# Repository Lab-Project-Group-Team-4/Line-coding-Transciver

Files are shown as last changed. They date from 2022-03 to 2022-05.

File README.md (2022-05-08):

# Line-coding-Transciver
Line coding is a technique which is used to transmit a bit stream using a channel. There are several 
globally recognized standard line-coding schemes available in the world. This paper focuses on the 
development and implementation of a simplex line coding transceiver based on analog components 
and IC’s such as OpAmps, transistors and signal generating ICs. This project aims to accomplish 
data between two microcontrollers via a pair of twisted wires transmission with a data length of 1000 
bits at a minimum data rate of 10 kb/s

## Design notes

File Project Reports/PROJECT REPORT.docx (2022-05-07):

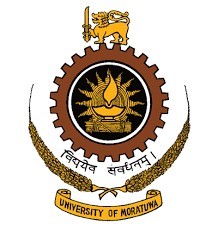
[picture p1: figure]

Department of Electronic & Telecommunication Engineering

University of Moratuwa

Simplex Line Coding Transceiver

Group 04

Ayodya W.K.H | 190065K
Bandara D.P.S.D | 190070V
Bandara D.R.K.W.M.S.D | 190071B
Bandara E.M.D.A | 190072E

Supervisor: Mr. Mevan Wijewardena

This report is submitted as partial fulfilment of module EN2090 - Laboratory Practice - II

Date of Submission: 07th May 2022

Table of Content

| Page
Abstract | i
1. Introduction | 3
2. Methodology 2.1. Block Diagrams 2.2. Encoder Circuit 2.2.1. Specifications 2.2.2. Circuit 2.2.3. Calculations 2.2.4. Simulation 2.2.5. PCB 2.2.6. Enclosure Design 2.3. Decoder Design 2.3.1. Specifications 2.3.2. Circuit 2.3.3. Simulation 2.3.4. PCB 2.3.5. Enclosure Design | 3 - 4 4 - 7 4 5 5 6 6 - 7 7 7 - 9 7 8 8 9 9
3. Results | 10
4. Discussion | 10
5. Acknowledgements | 11
6. References /Bibliography | 11
7. Contribution | 11
8. Appendices | 11 - 18

Project Report – Semester 3 May 2022

Simplex Line Coding Transceiver

Group 4

Dept. of Electronic and Telecommunication Engineering, University of Moratuwa

ABSTRACT

Line coding is a technique which is used to transmit a bit stream using a channel. There are several globally recognized standard line-coding schemes available in the world. This paper focuses on the development and implementation of a simplex line coding transceiver based on analog components and IC’s such as OpAmps, transistors and signal generating ICs. This project aims to accomplish data between two microcontrollers via a pair of twisted wires transmission with a data length of 1000 bits at a minimum data rate of 10 kb/s.

1. INTRODUCTION

The simplex line coding transceiver transmits specific length bits via a pair of twisted wires in one direction from one location to another. The transmitter and the receiver operate on the same frequency. This project aims to transmit a large bit length at a high bit rate with a low error rate. We have designed and built an encoding circuit and a decoding circuit that includes all analog devices. We chose the Manchester encoding system as our encoding technology.

2. METHODOLOGY

Manchester Encoding scheme has been implemented in our design using separate encoder and decoder circuits connected by a 50cm long twisted pair cable.

  2.1. Block Diagrams

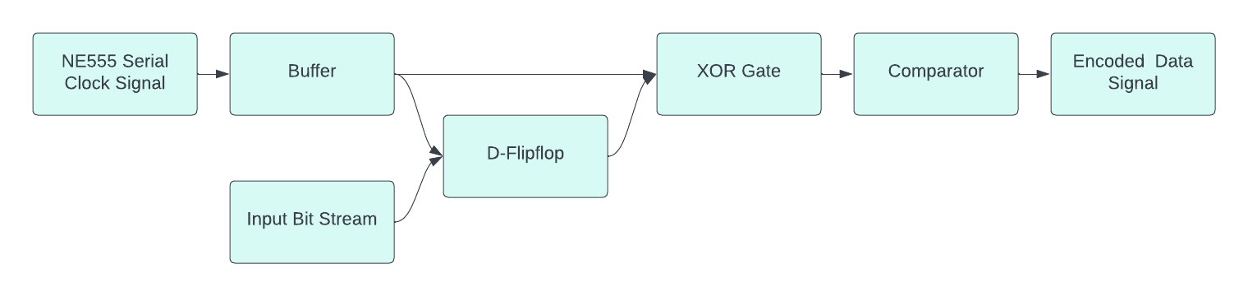
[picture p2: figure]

Figure 2.1.1: Encoder Block Diagram

- D flip flop: Syncing Data signal with the clock input
- Clock Buffer Circuit: To introduce a delay to clock pulse.
- XOR Gate: Apply XOR operation on clock and data signals to produce the output as 0V - 5V signal
- Comparator: Convert signal in to -5V to +5V signal to produce Manchester Signal

Figure 2.1.1: Decoder Block Diagram

- Transistor switches: Used to remove the rapid pulses in the Manchester signal
- Comparator: Used to remove the distortions which is added by transistor switches and make a clean signal
- Holding and thresholding part: Use to hold the levels for a fixed period.
  2.2. Encoder Design

Encoder encodes digital data into a digital signal using Manchester encoding scheme. In Manchester encoding, ‘0’s are encoded as falling edges and ‘1’s are encoded as rising edges. The main advantage of using Manchester encoding is its self-clocking and synchronization on mid-bit transition. Manchester encoded data is achieved by sending digital data and clock through an XOR gate.

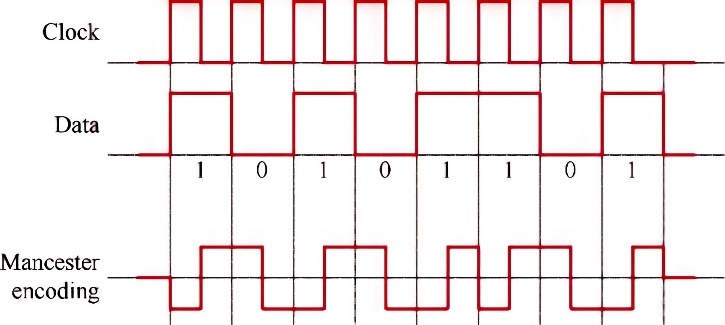
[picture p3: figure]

Figure 2.2: Manchester Encoding Scheme

    2.2.1. Specifications

Baud Rate : 10 kb/s

Current Drawn : 46 mA

Operating Voltages : 8 – 24 V

Impedance : 92 kΩ

    2.2.2. Circuit

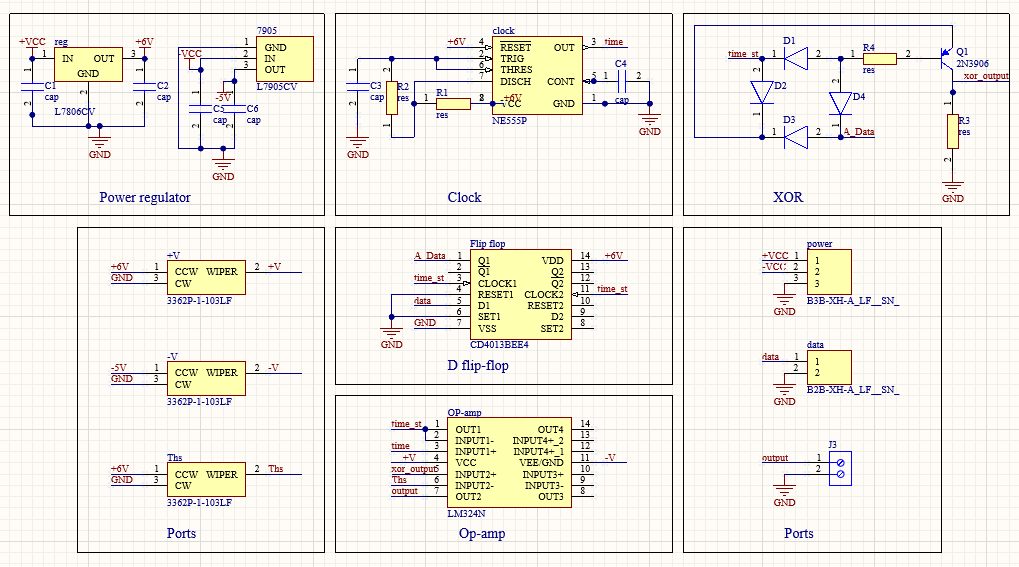
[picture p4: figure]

Figure 2.2.2: Encoder Schematic Design

    2.2.3. Calculations

The following calculations are used to derive the clock frequency and the duty cycle of the NE555 timer.

Frequency of Oscillation,

R1 = 220 Ω

R2 = 5600 Ω

C1 = 10 nF

f=1/T=(1⋅44)/((R_1 +2R_2 )C_1) = (1⋅44)/((220+2×5600)×10×10 ^(-9)) = 12 kHz

Duty Cycle,

(t_1)/(t_1 +t_2)=(R_1 +R_2)/(R_1 +2R_2)=1-(R_2)/(R_1 +2R_2) = 1-5600/(220+2×5600) = 50%

    2.2.4. Simulation

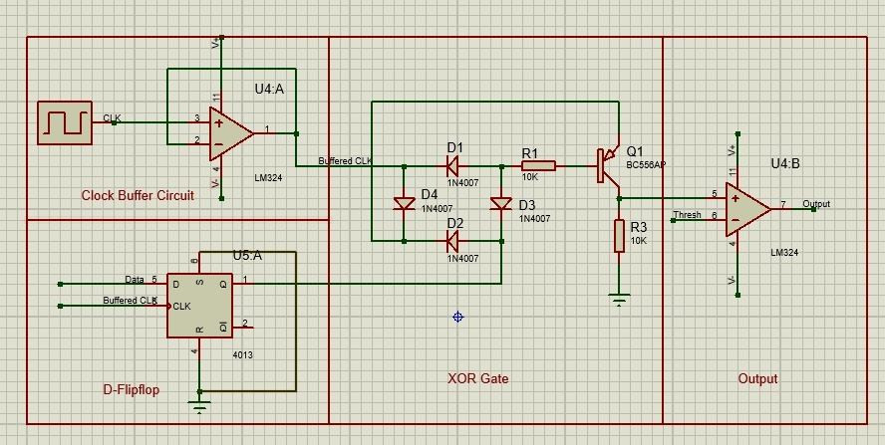
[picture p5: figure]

Figure 2.3.3: Encoder Simulation

    2.2.5. PCB Design

Size of the PCB : 9cm x 5cm

Components mounted on Encoder PCB

- LM7905 Voltage Regulator - 1
- LM7806 Voltage Regulator - 1
- CD4013B D-Flipflop IC - 1
- NE555 Timer - 1
- LM324N OpAmp - 1
- BC556 PNP Transistor - 1
- Capacitors
  - 100 nF Polarized Cap - 2
  - 10 nF Ceramic Cap - 1
  - 100 nF Ceramic Cap - 1
  - 330 nF Polarized Cap - 2
- Resistors
  - 10 kΩ - 2
  - 5.6 kΩ - 1
  - 220 Ω - 1
- 1k Potentiometer - 3
- 1N4007 Diodes - 4
- 3 pin JST Connector - 1
- Screw Terminal - 1

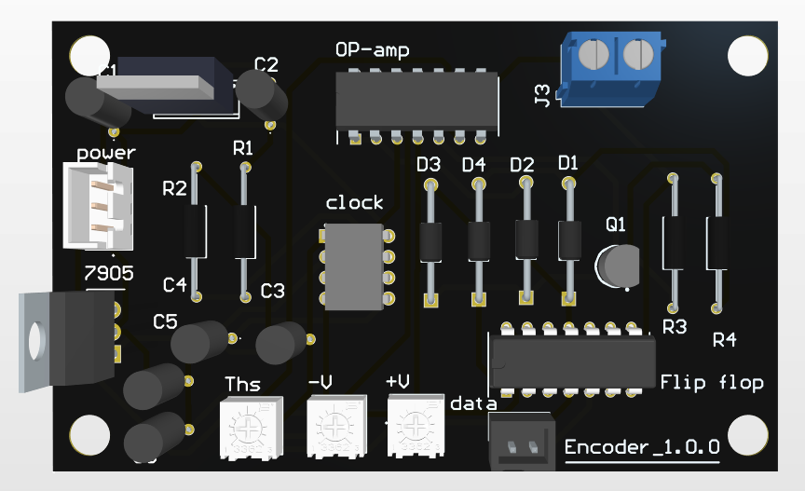
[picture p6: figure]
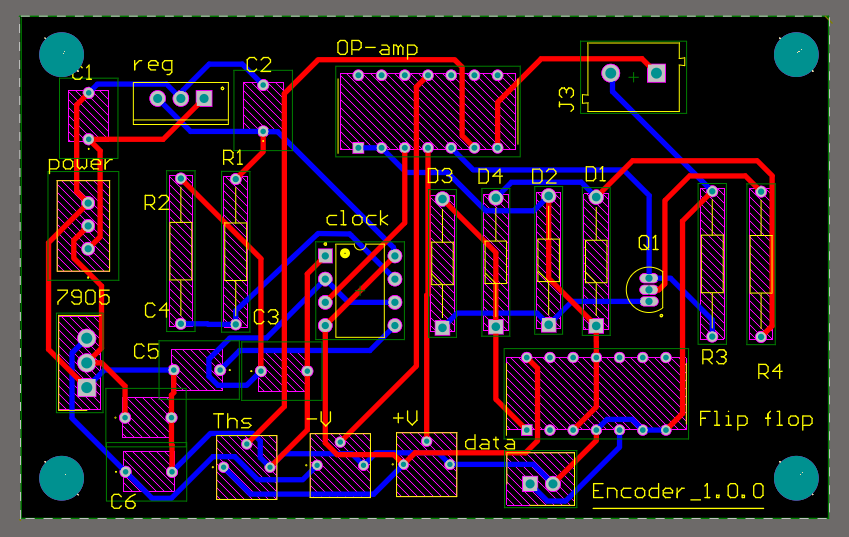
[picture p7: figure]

Figure 2.2.5.1: Encoder PCB 3D Model Figure 2.2.5.2: Encoder PCB Design

    2.2.6. Enclosure Design

The enclosure is design with a glossy finish to get a futuristic appearance.

Material : PLA+ Plastics

Size of the Enclosure : 9cm x 5.6cm x 5.6cm

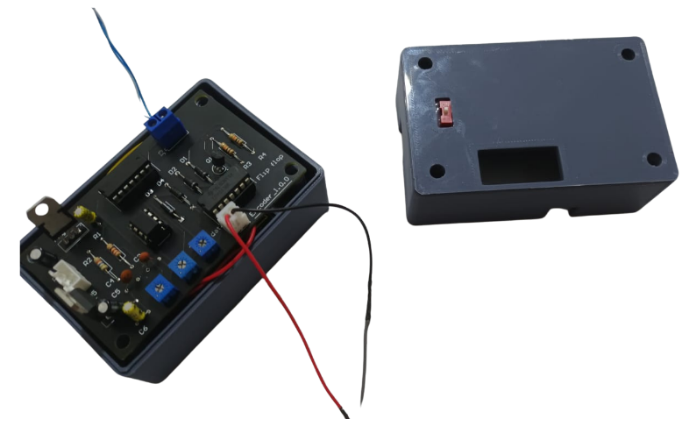
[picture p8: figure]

Figure 2.2.6: Encoder Enclosure Design

  2.3. Decoder Design

The decoding circuit consist only analog components. When the encoded Manchester signal is received, the encoded data is decoded by the decoder. The decoder circuit operates at a frequency very similar to the encoder circuit.

    2.3.1. Specifications

Baud Rate : 10 kb/s

Current Drawn : 17 mA

Operating Voltages : 8 – 24 V

Impedance : 92 kΩ

    2.3.2. Circuit

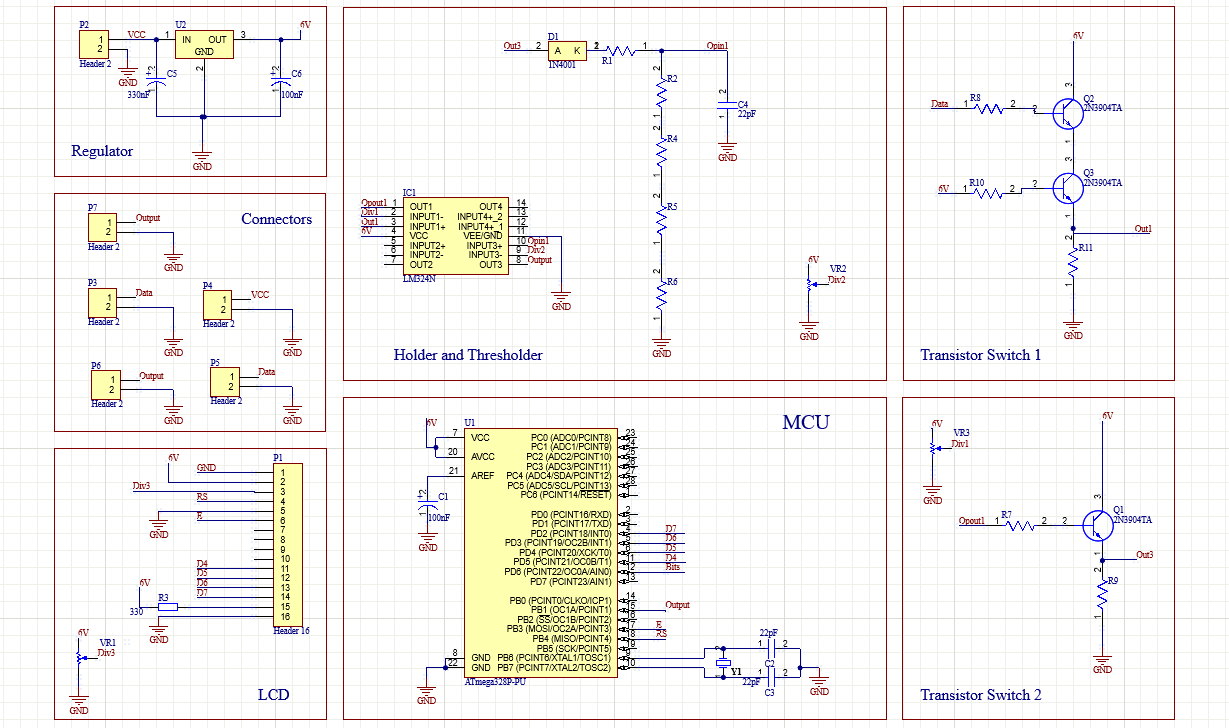
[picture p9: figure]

Figure 2.3.2: Decoder Schematic Design

    2.3.3. Simulation

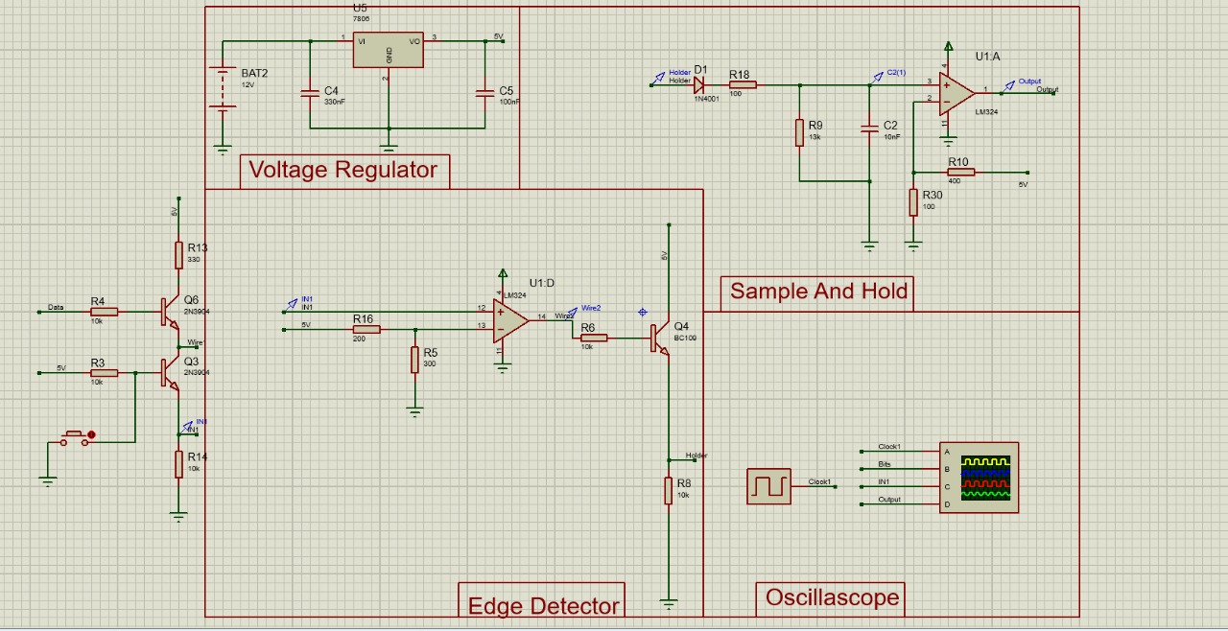
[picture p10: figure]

Figure 2.3.3: Decoder Simulation

    2.3.4. PCB Design

Size of the PCB : 9cm x 5cm

Components mounted on Encoder PCB

- LM7806 Voltage Regulator - 1
- LM324N OpAmp - 1
- 2N3904TA NPN Transistor - 1
- Capacitors
- 100nF Polarized cap - 1
- 330nF Polarized cap - 1
- 10nF ceramic Cap - 1
- Resistors
  - 100Ω - 1
  - 10kΩ - 6
  - 1KΩ - 3
- 1k Potentiometers - 2
- 1N4001 Diodes - 1
- 2 pin JST Connectors - 4

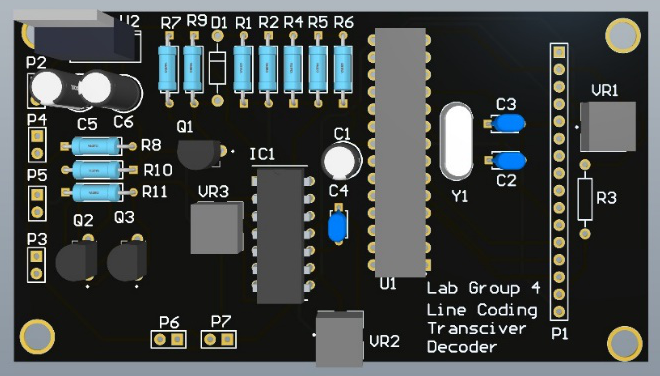
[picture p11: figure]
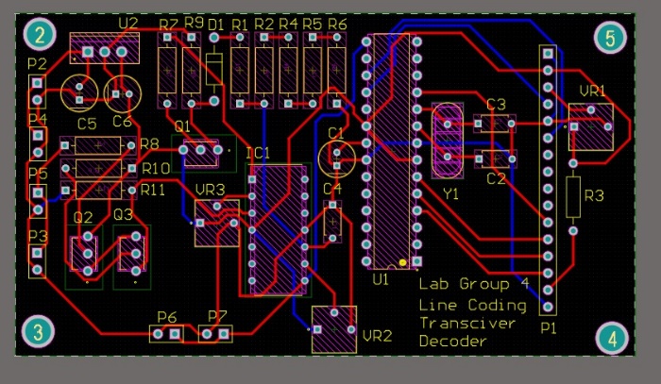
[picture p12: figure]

Figure 2.3.4.1: Decoder PCB 3D Model Figure 2.3.4.2: Decoder PCB Design

    2.3.5. Enclosure Design

The enclosure is design with a glossy finish to get a futuristic appearance.

Material : PLA+ Plastics

Size of the Enclosure : 13cm x 9cm x 4.5cm

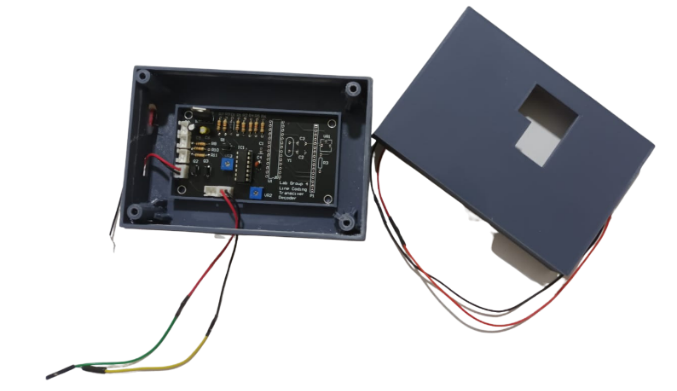
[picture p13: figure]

Figure 2.3.5: Decoder Enclosure Design

3. RESULTS

10kb/s input has been input to the simplex line code transceiver using an Arduino Uno microcontroller. The bit pattern consists of a repetitive bit pattern with length of 10bits. Yellow colour signal in the oscilloscope output indicates transmitting signal. The encoder has converted the binary bit pattern to a Manchester signal with peak values of +5V and -5V. The decoder has used pulse width identification mechanism to decode the signal. Blue color waveform in the oscilloscope indicates the output waveform. The delay between the encoded Manchester signal and the decoded output is around 10µs. There is no observable delay between the input signal and the Manchester encoded signal.

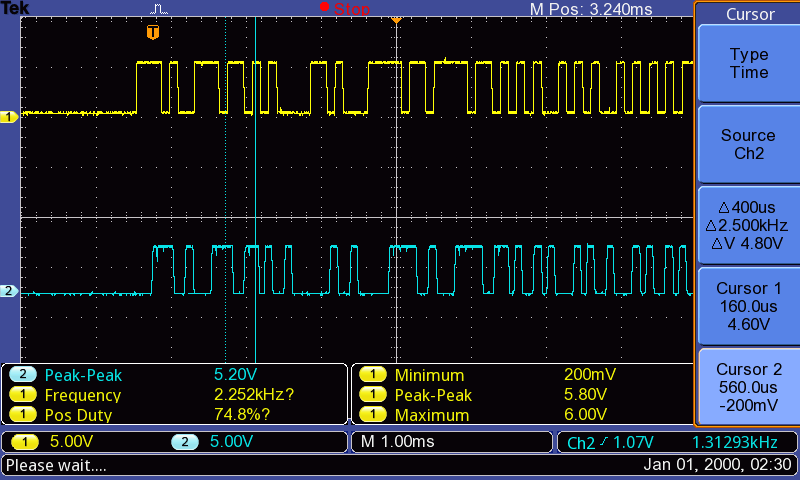
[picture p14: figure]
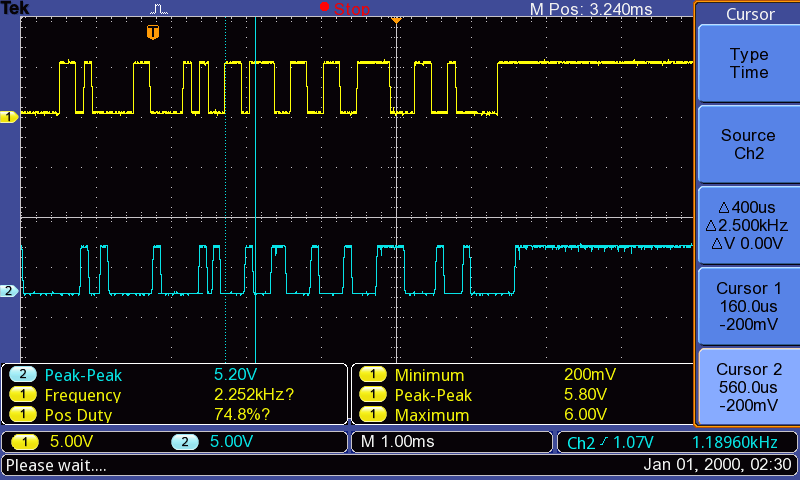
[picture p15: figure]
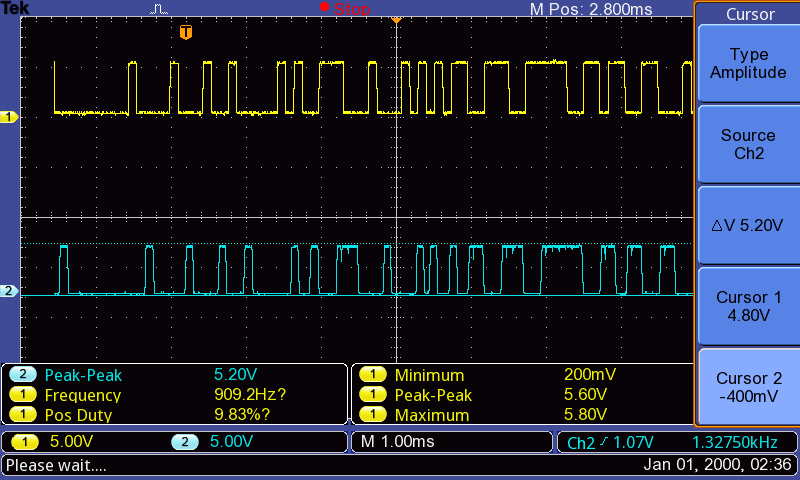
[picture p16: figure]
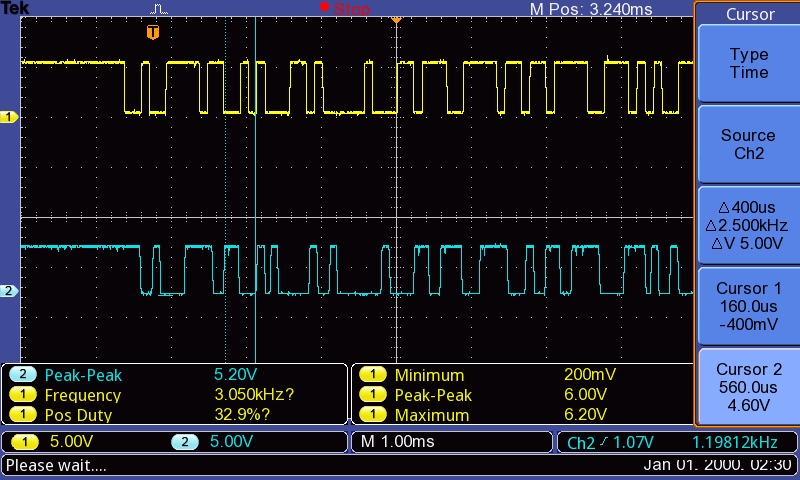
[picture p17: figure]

Figure 3.1: Data Signal and Decoded Output Signal

4. DISCUSSION

We had to face a lot of challenges in designing and implementing the Simplex line coding transceiver.

Problems faced while carrying on the project

- Several iterations of tuning needed when connecting sub-sections of the circuit
- Some ICs and components bought from local vendors operated differently than the specifications in official datasheets
- Scarcity of some components has led to difficulties when building the circuit

Solutions for these problems

- Planning input-output configurations and setting benchmarks for each subsection
- Pre-testing each component before adding to circuit to verify its behavior.
- Using readily available ICs and components for the design. Contact electronic equipment vendors and check the availability of components before adding them to circuit
5. ACKNOWLEDGEMENT

We would like to pay our gratitude to our supervisor Mr. Mevan Wijewardena who always encouraged self-studying and constantly guided us whenever we needed help. The meetings held by our supervisor were very helpful to clear our doubts and discuss issues regarding the project. In addition, we would like to convey our sincere gratitude to all the lecturers and instructors who were always willing to share their knowledge with us. It is our duty to thank our ENTC family, without whom we could not have accomplished this project. Everyone in our batch helped each other and learnt everything together.

We developed team spirit working together in this project for about 3 months and all our group members gave their maximum contribution to succeed the given project. Further, we would like to thank all the people who are not mentioned here for the great support provided.

6. REFERENCES/BIBLIOGRAPHY

[1] https://www.allaboutcircuits.com/technical-articles/how-to-generate-manchester-encoded-data-in-hardware-and-firmware/

[2] https://www.allaboutcircuits.com/technical-articles/how-to-decode-manchester-encoded-data-using-hardware/

[3] https://www.ti.com/lit/ds/symlink/lm555.pdf

7. CONTRIBUTION

190065K | Ayodya W.K.H | Decoder Circuit Design, Decoder Enclosure Design, PCB Soldering
190070V | Bandara D.P.S.D | Encoder Circuit Design, Encoder PCB Design, PCB Soldering
190071B | Bandara D.R.K.W.M.S.D | Decoder Circuit Design, Decoder PCB Design, PCB Soldering
190072E | Bandara E.M.D.A | Encoder Circuit Design, Encoder Enclosure Design, PCB Soldering

8. APPENDICES

GitHub Repository : https://github.com/Lab-Project-Group-Team-4/Line-coding-Transciver/tree/master

Enclosure CAD Designs :

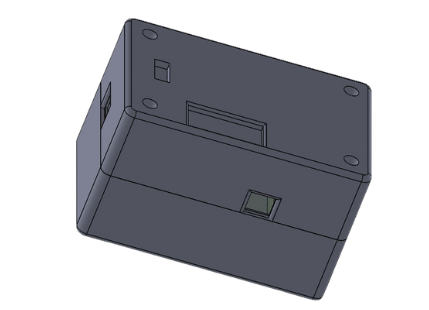
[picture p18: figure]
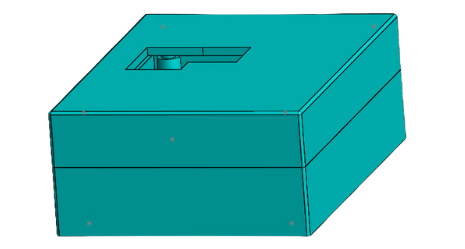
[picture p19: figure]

Figure 7.1: Encoder CAD Design Figure 7.2: Decoder CAD Design

Encoder Code :

//including libraries for interrupt and delay

#include <avr/io.h>

#include <util/delay.h>

//delay amount in micro-seconds

#define delay_amount 70

//Data String Given

String Data = "1010101010";

int len = 10; //length of the String

int index = 0; //Current bit index in patter

int i = 0; //transmitted bit value

void setup() {

DDRB |= (1<<PB0); // Configuring Port B pin0 as an output

}

void loop() {

if ( i < 1000 )

{

//toggle output based on the bit value

if (Data[index%len] == '0'){

PORTB &= ~(1<<PB0);

}

else{

PORTB |= (1<<PB0);

}

index = (index + 1)%len;

_delay_us(delay_amount);

}

i++;

}

Decoder Code :

#include <SPI.h>

#include <SD.h>

#define length_arr 300

File myFile;

int bit_array[length_arr] = {0};

int bit_pattern[10] = {0, 1, 0, 1, 0, 1, 0, 1, 0, 1};

int index = 0;

volatile bool start_read = false;

volatile bool read_val = false;

void blink_LED(int delay_amount);

float accuracy(int* encoded, int* decoded ,int len_message);

void setup() {

DDRD &= ~(1<<PD7); // Set pin D7 as input

DDRD |= (1<<PD6); // Set pin D6 as output

PORTD |= (1<<PD7); // Pull-Up the pin 7

// TIMER 0 for interrupt frequency 10000 Hz:

cli(); // stop interrupts

TCCR0A = 0; // set entire TCCR0A register to 0

TCCR0B = 0; // same for TCCR0B

TCNT0 = 0; // initialize counter value to 0

// set compare match register for 10000 Hz increments

OCR0A = 199; // = 16000000 / (8 * 10000) - 1 (must be <256)

// turn on CTC mode

TCCR0B |= (1 << WGM01);

// Set CS02, CS01 and CS00 bits for 8 prescaler

TCCR0B |= (0 << CS02) | (1 << CS01) | (0 << CS00);

// enable timer compare interrupt

TIMSK0 |= (1 << OCIE0A);

sei();

}

void loop() {

if (read_val && index < length_arr) {

bit_array[index] = ((PIND & ( 1 << PD7 ))) >> 7;

read_val = false;

index++;

}

else if ( index == length_arr) {

Serial.begin(9600);

for ( int i = 0; i < length_arr; i++) {

Serial.print(bit_array[i]);

Serial.print(";");

if ( i%50 == 0){

Serial.println();

}

}

float accuracy_val;

accuracy_val = accuracy(bit_pattern, bit_array, length_arr);

Serial.println();

Serial.end();

index++;

}

}

ISR(TIMER0_COMPA_vect) {

read_val = true;

}

float accuracy(int* encoded, int* decoded ,int len_message){

int correct = 0;

int message_index = 0;

for ( int i = 0; i<len_message ; i++){

if (decoded[i] == encoded[message_index] ) {

correct++;

}

message_index = (message_index + 1 ) % 10;

}

}

Datasheet

Features

1. Encoder

Current Drawn | 46 mA
Operating Voltage | 8 - 24 V
Impedance | 92 kΩ
PCB Dimension | 9cm x 5cm
Enclosure Dimension | 9cm x 5.6cm x 5.6cm

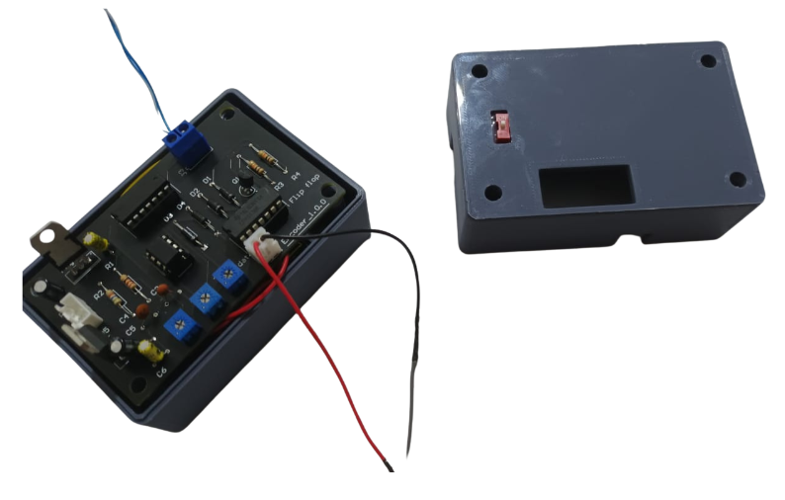
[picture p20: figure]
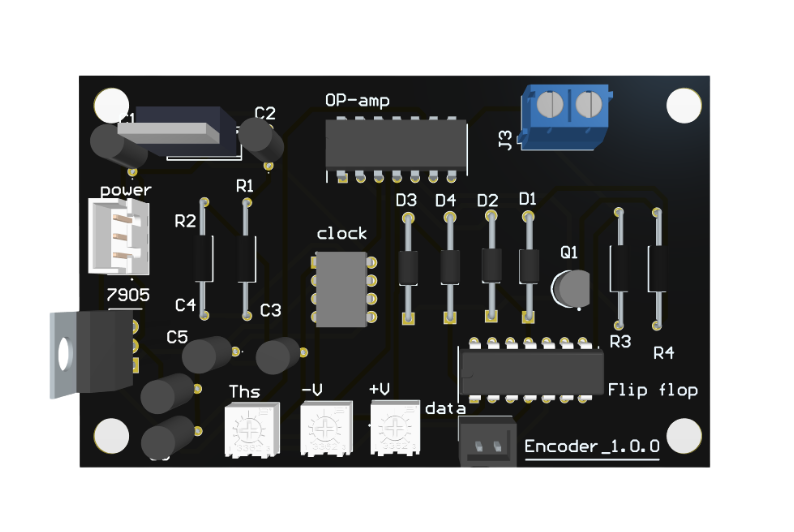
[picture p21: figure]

Figure 1.1: Encoder PCB Design

Figure 1.2: Encoder Enclosure Design

2. Decoder

Current Drawn | 17 mA
Operating Voltage | 8 - 24 V
Impedance | 92 kΩ
PCB Dimension | 9cm x 5cm
Enclosure Dimension | 13cm x 9cm x 4.5cm

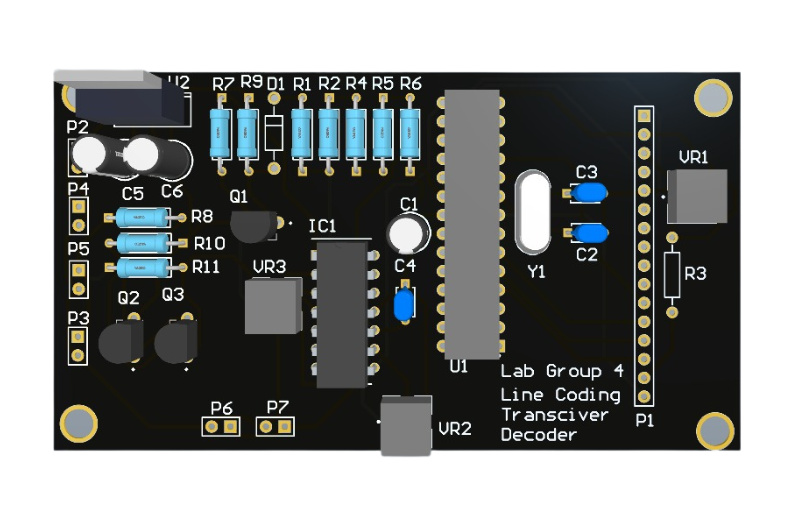
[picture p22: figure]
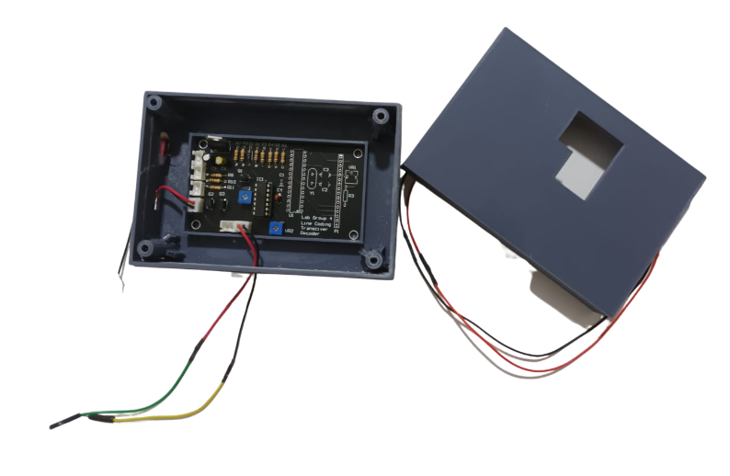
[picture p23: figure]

Figure 1.2: Decoder Enclosure Design

Figure 2.1: Decoder PCB Design

Signal Specifications

Encoded Signal : +5 to -5V

Decoded Output Signal : 0 to 5V

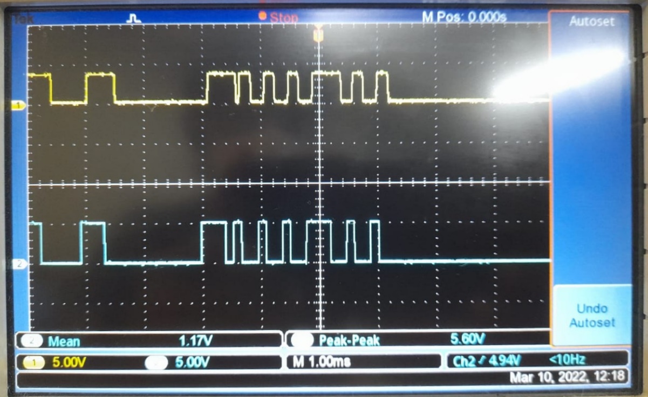
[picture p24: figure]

Figure: Data Signal and Decoded Output Signal

Product Specifications

Encoding Method | Manchester Encoding Scheme
Tested Maximum Transfer Distance | 5m
Power Source | 9V Battery

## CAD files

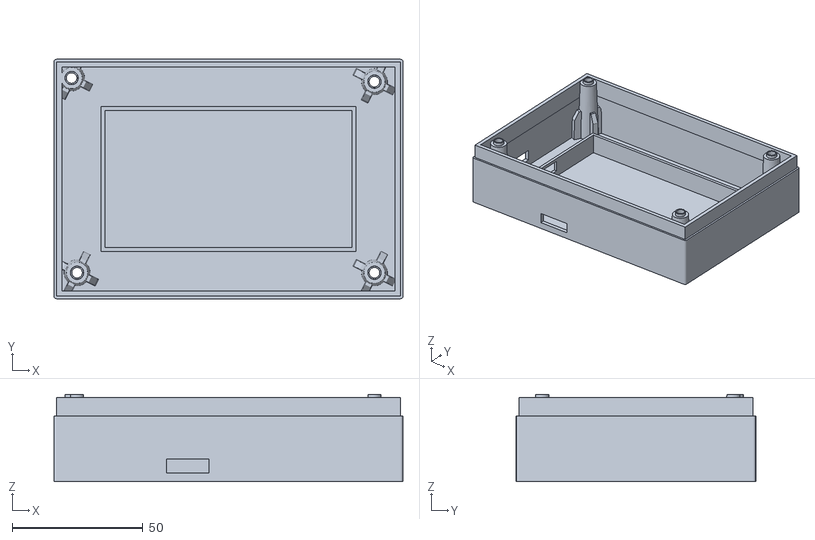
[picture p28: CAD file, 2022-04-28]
LabProjectEnclosures/encbottom/PCB_DecoderBottom.STL
133.2 x 91.4 x 33.2

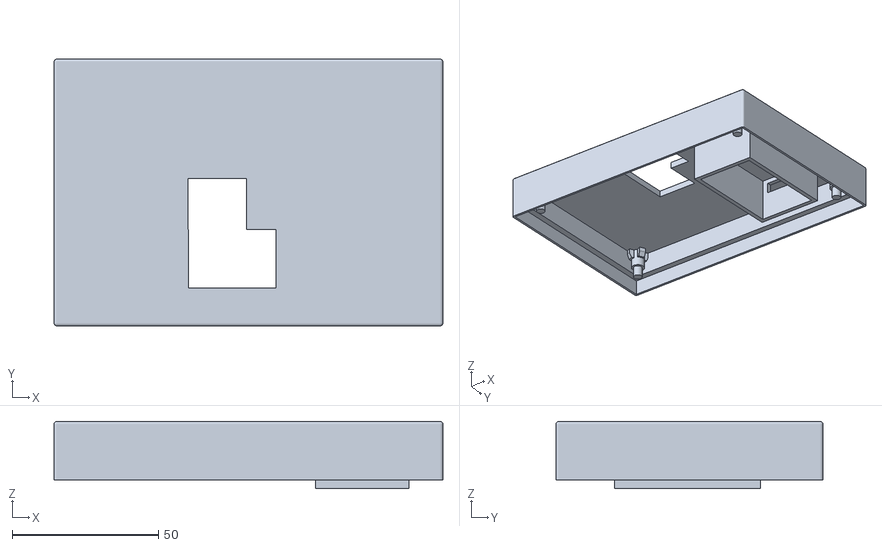
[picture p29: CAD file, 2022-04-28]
LabProjectEnclosures/enctop/PCB_DecoderTop.STL
133.2 x 91.4 x 23.0

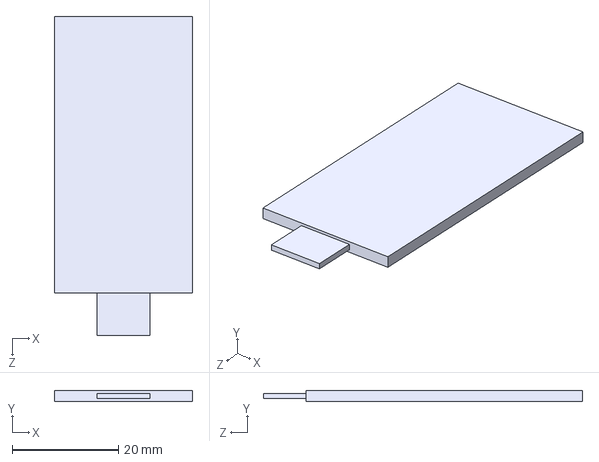
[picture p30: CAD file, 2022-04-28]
LabProjectEnclosures/Part11.STEP
26.0 x 2.00 x 60.0 mm

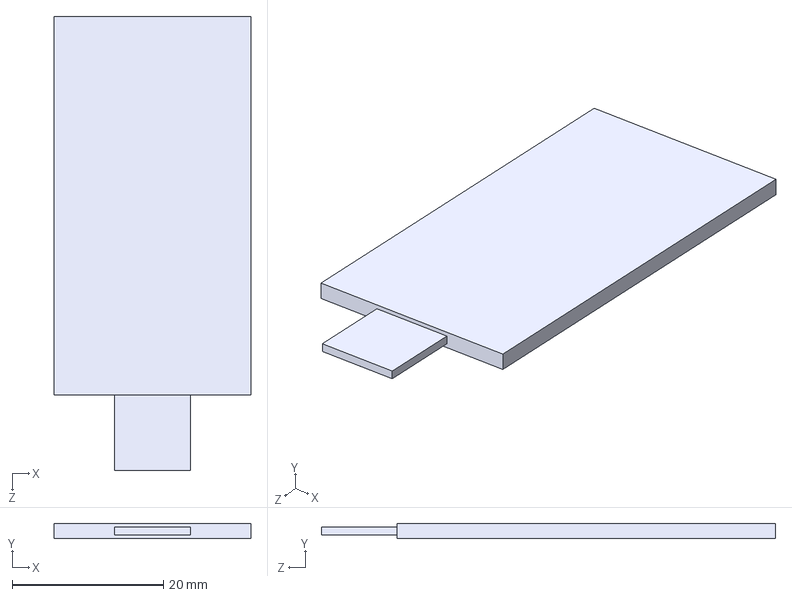
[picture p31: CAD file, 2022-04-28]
LabProjectEnclosures/Part13.STEP
26.0 x 2.00 x 60.0 mm

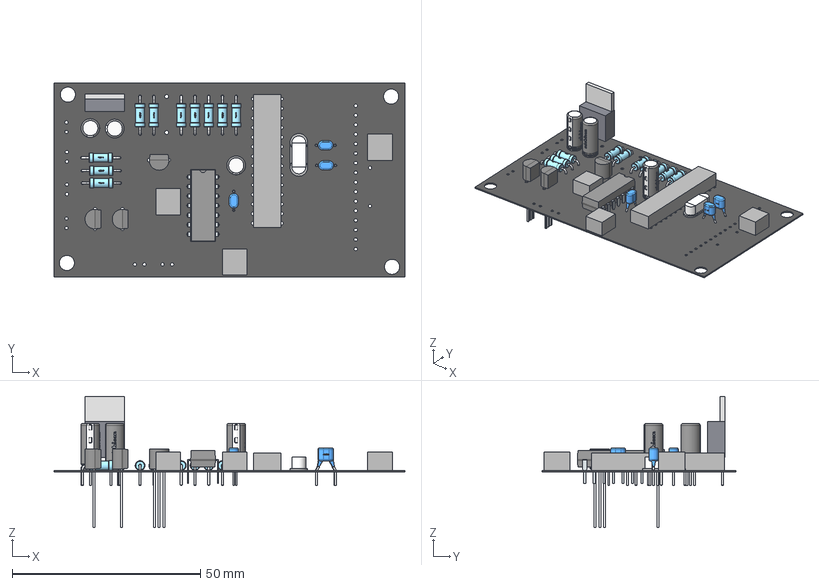
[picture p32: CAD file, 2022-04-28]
LabProjectEnclosures/PCB_Decoder.step
93.2 x 51.4 x 34.9 mm
Extruded x 8
PinsArrayLR
leads x 3
vent x 3
marking x 3
bottom x 3
logo x 3
Lead x 3
Murata x 3

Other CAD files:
LabProjectEnclosures/Part11.SLDPRT

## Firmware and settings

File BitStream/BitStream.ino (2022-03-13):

int bitsize = 150;
int Data[300];
int Result[300];
int clockc[300];
int signalc[300];
void setup() {

  pinMode(7, OUTPUT);
  pinMode(8, OUTPUT);
  pinMode(9, INPUT);
  pinMode(6, OUTPUT);
  digitalWrite(8, 1);
}

void loop() {
  for (int j = 0; j < bitsize; j++) {
    int dt = rand() % 2;

    Data[2 * j] = dt;
    Data[2 * j + 1] = dt;
    clockc[2 * j] = 1;
    clockc[2 * j + 1] = 0;

  }
  for (int j1 = 0; j1 < bitsize * 2; j1++) {
    signalc[j1] = Data[j1] ^ clockc[j1];
  }


  for (int i = 0; i < bitsize * 2; i++) {
    digitalWrite(8, clockc[i]);
    digitalWrite(7, signalc[i]);
    digitalWrite(6, Data[i]);

    delayMicroseconds(45);
    //delay(5);
    //digitalWrite(8, 0);
    //delayMicroseconds(50);
    //delay(5);
    int a = digitalRead(9);
    Result[i] = a;
    //Serial.print(a);
    //Serial.print(" ");


  }
  //Serial.println();
  int count = 0;
  for (int i = 0; i < bitsize*2; i++) {
    if (Data[i] != Result[i]) {
      count += 1;
    }
  }
//  Serial.print("Number of Errors: ");
//  Serial.println(count);
  //  delay(1000);


}

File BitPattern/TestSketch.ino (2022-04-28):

#include<LiquidCrystal.h>


int n = 400;
int* Data = new int[n];
int* res = new int[n];
LiquidCrystal LCD(12, 11, 5, 4, 3, 2);
void setup() {

  pinMode(9, INPUT);
  pinMode(6, OUTPUT);
  LCD.begin(16, 2);
  
}

void loop() {

  for (int j = 0; j < n; j++) {
    int dt = rand() % 2;
    Data[j] = dt;
  }

  for (int i = 0; i < n; i++) {
    digitalWrite(6, Data[i]);
    delayMicroseconds(100);
    int a = digitalRead(9);
    res[i] = a;
  }
  int count = 0;
  for (int i = 0; i < n; i++) {
    if (Data[i] != res[i]) {
      count += 1;
    }
  }
  LCD.print("Errors: ");
  LCD.print(count);
  
  delay(10);
  LCD.clear();

}

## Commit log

2021-12-25 Decoder circuit
2022-03-11 final circuit after testing
2022-03-13 Decoder with clock algning circuit
2022-04-28 Final decoder circuit after testing, using PWM averaging principle to decode without clock'
2022-04-28 Final PCB ,Printed
    [Line Coding Transceiver_Decoder.PrjPcb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]
2022-04-28 Final enclosures of Encoder and Decoder
    [PCB_Decoder.step, PCB_DecoderBottom.STL, PCB_DecoderTop.STL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]
